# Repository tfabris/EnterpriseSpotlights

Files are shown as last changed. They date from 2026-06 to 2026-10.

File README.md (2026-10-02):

LED Spotlights for Enterprise Refit Models
==========================================
&copy; 2026 by Tony Fabris

https://github.com/tfabris/EnterpriseSpotlights

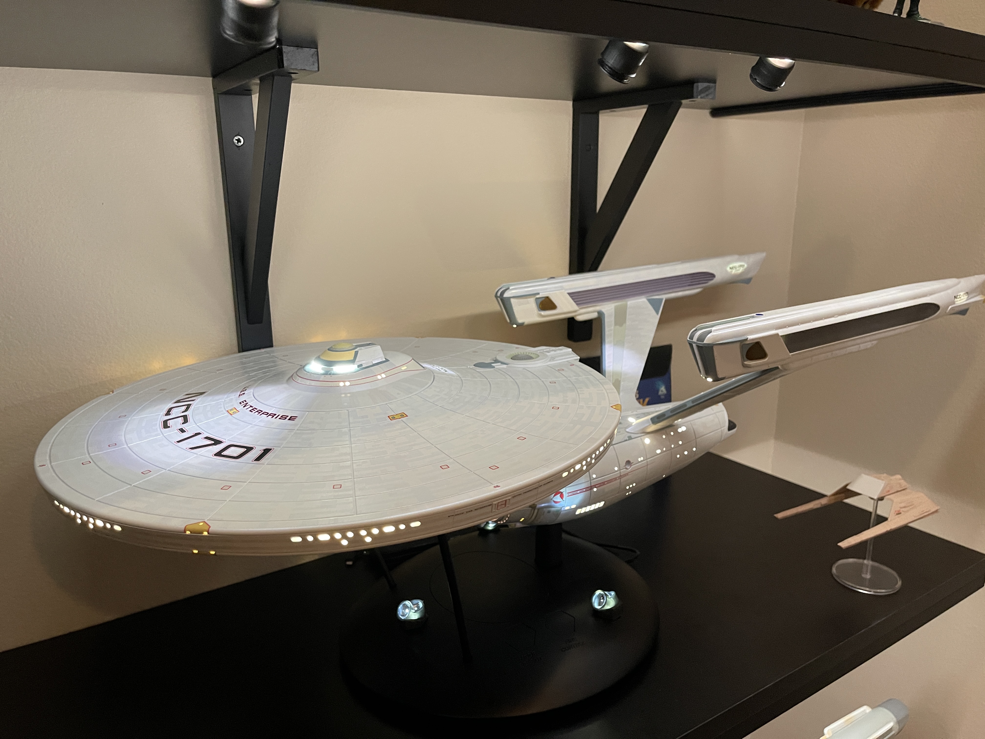
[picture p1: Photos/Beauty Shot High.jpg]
Beauty Shot


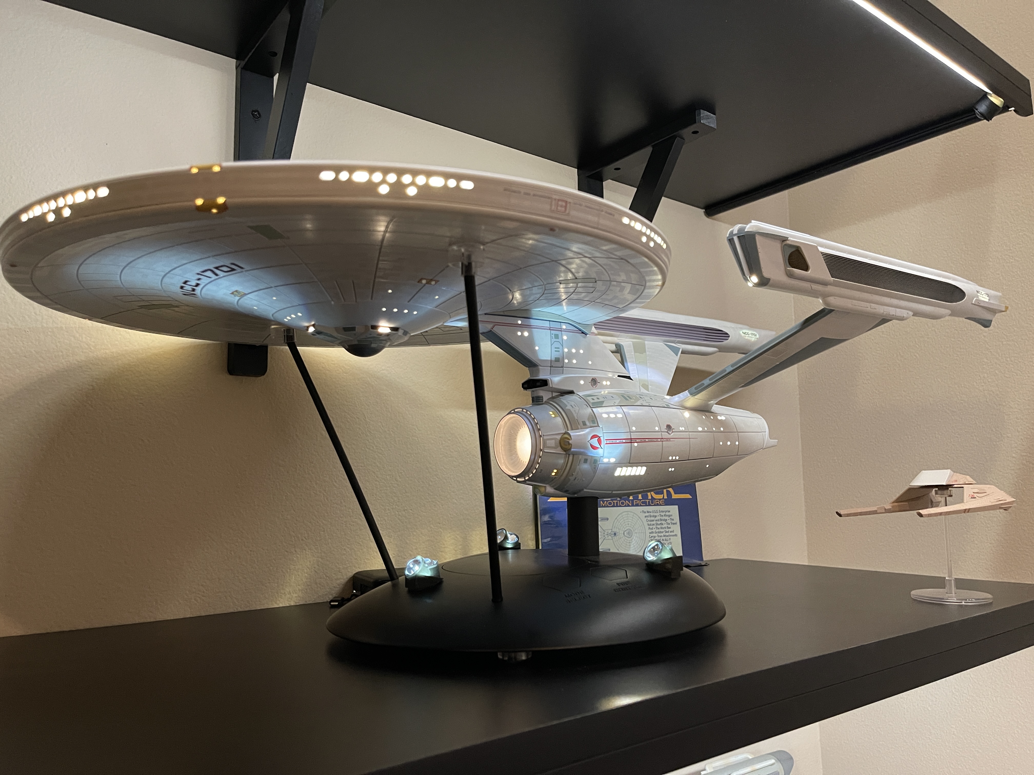
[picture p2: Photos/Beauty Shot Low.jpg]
Beauty Shot
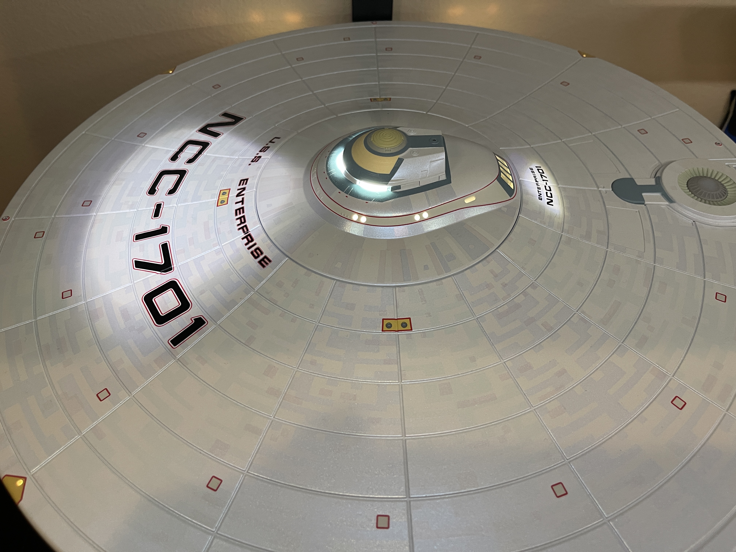
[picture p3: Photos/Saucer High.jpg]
|  |  |
| ---|---|
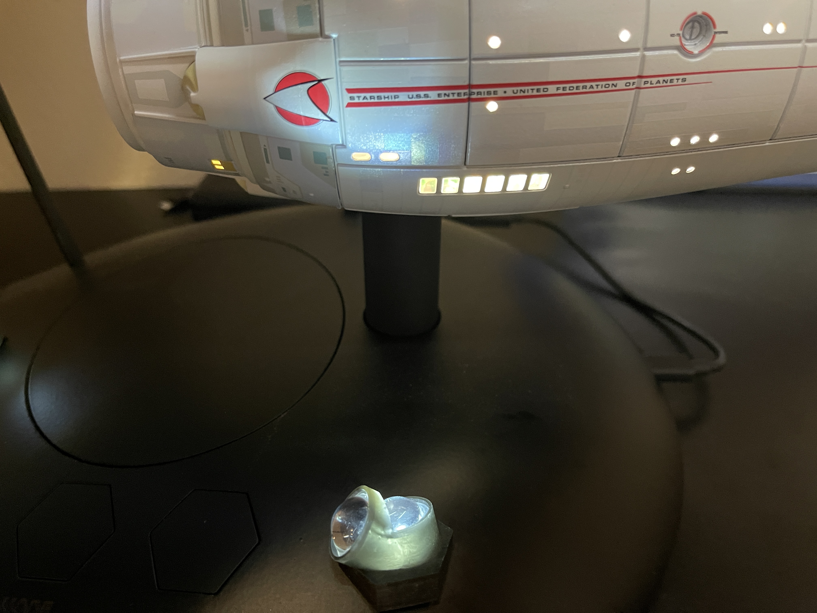
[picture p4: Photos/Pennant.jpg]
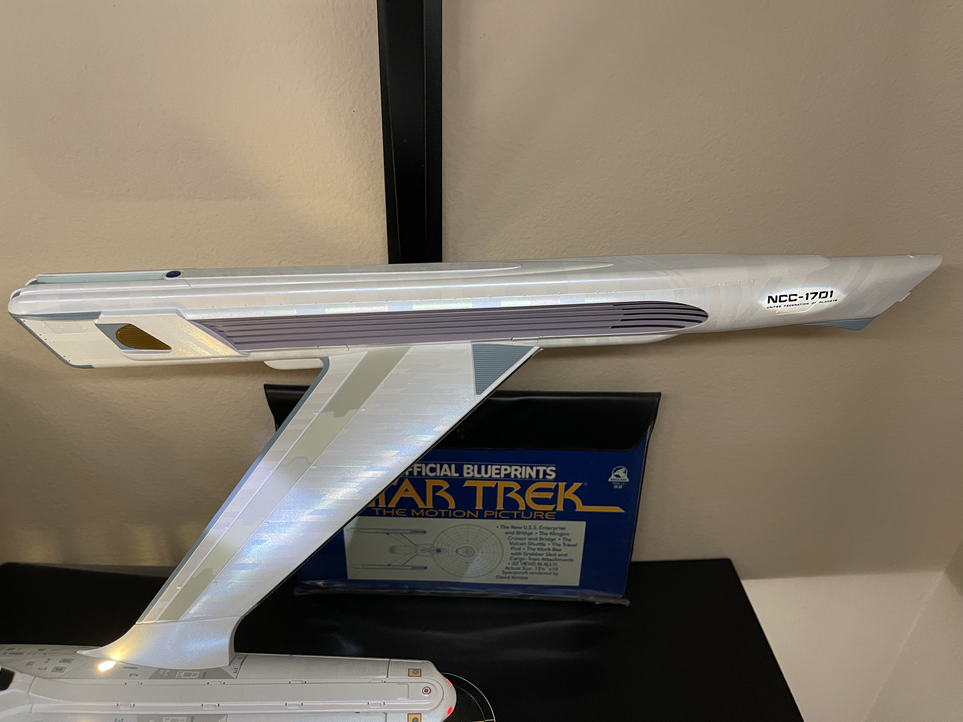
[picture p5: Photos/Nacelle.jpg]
|  |  |

#### This Project:

3D printed assemblies to project hull spotlights onto replica models of the Enterprise Refit from "Star Trek: The Motion Picture". I am using these for my Tomy brand die-cast replica of the Enterprise, but these could also theoretically be repurposed for other similar models such as a Polar Lights Enterprise kit.

#### The Problem:

When making the movie, the special effects artists lit the Enterprise's hull with spotlights. It is implied in the movie that these are all self-lights, like the ones which shine on the insignia of a cruise ship or a military vessel. But in the movie, those spotlights weren't actually self-lights. They were studio lights reflected via off-camera mirrors onto the hull of the Enterprise miniature.

This means it is nearly impossible to truly self-light a model kit or replica of the Refit Enterprise.

Many have tried. Some clever folks use a trick, commonly known as "Raytheon Lighting" among Enterprise kit builders, where LEDs are strategically positioned within the model's interior, to glow through the white plastic. Unfortunately, this technique causes its own difficulties, and it can't be used for my Tomy die-cast replica. Tomy **did** manage to Raytheon-light their outboard nacelle tips, which is incredibly helpful, since those are the most difficult ones to light.

#### My Solution:

Instead of trying to self-light the model, my system uses exterior lights, made of LEDs shining through lenses, to convincingly reproduce the spotlight effects seen in the movie. I chose direct illumination through lenses, rather than using mirrors, because these are less obtrusive than mirrors would have been.

Spotlight Fixtures
------------------

### Upper Spotlights:

I'm displaying my models on large 16" x 36" melamine shelves, and using 45° LED strip channel rails at the edges of the shelves to illuminate the models. Full details about the shelves and LED strips can be found here: https://github.com/tfabris/LED-Controller

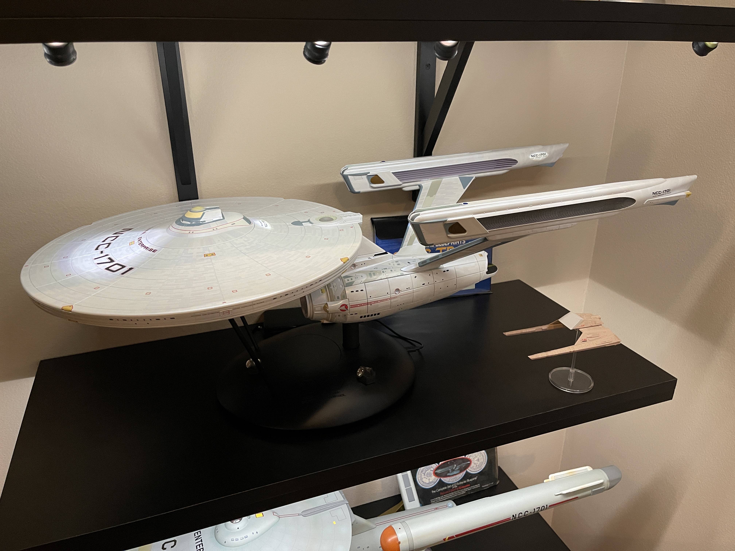
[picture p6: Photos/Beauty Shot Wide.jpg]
Beauty Shot


The LEDs strips I've installed into these channels are individually-addressable WS2812 programmable strips, commonly known as "NeoPixels". Most of the LEDs in the strips are set to a gentle glow to light my models, but, by programming specific single LEDs in the strips to shine brilliant white (I'm using RGB***W*** strips to get the extra ***white*** LEDs), I can mount some lenses in front of those particular LEDs to generate the spotlight effects.

That's where these 3D prints come in: The 3D printed lens holders snap into these rails, and each one holds two lenses in series, to allow a small amount of focusing. The 3D design has a semi ball joint, which allows a small amount of aiming (up/down about 22 degrees from center, and left-right about 10 degrees from center).

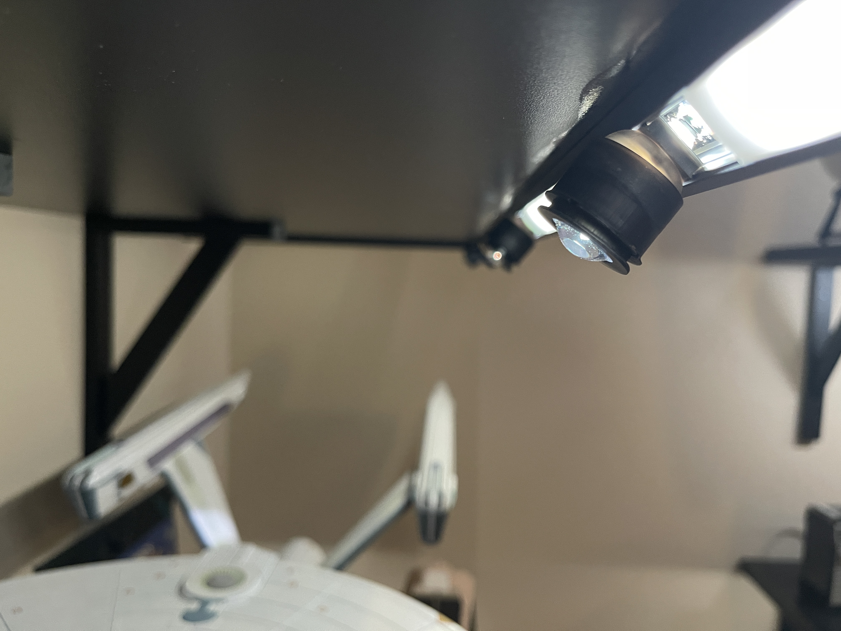
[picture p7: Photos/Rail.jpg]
Rail
    
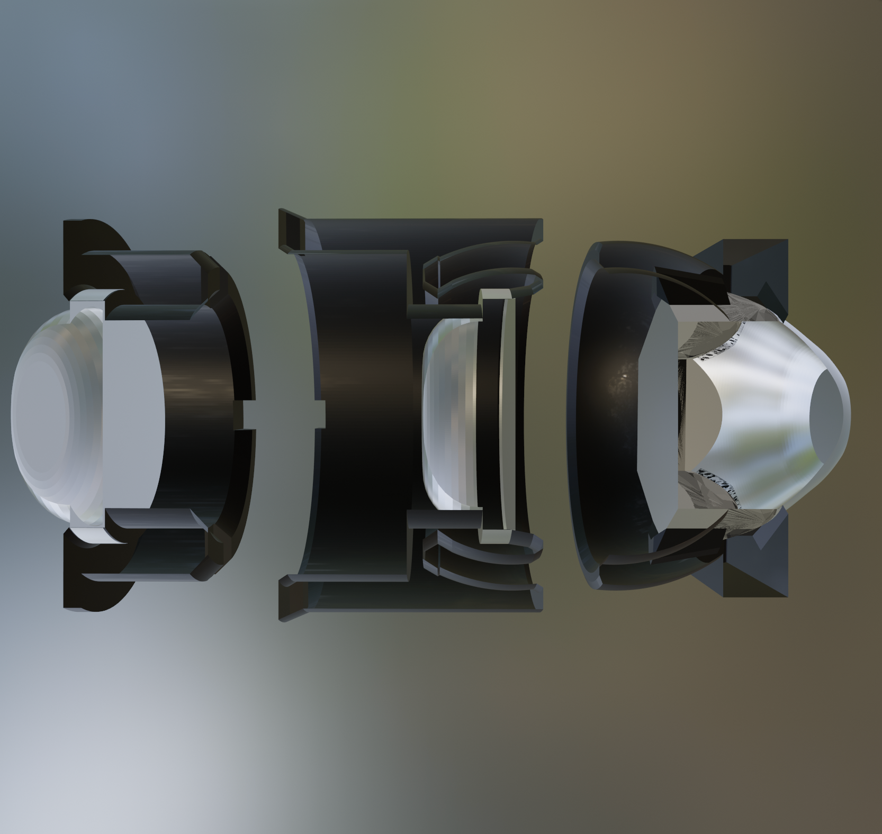
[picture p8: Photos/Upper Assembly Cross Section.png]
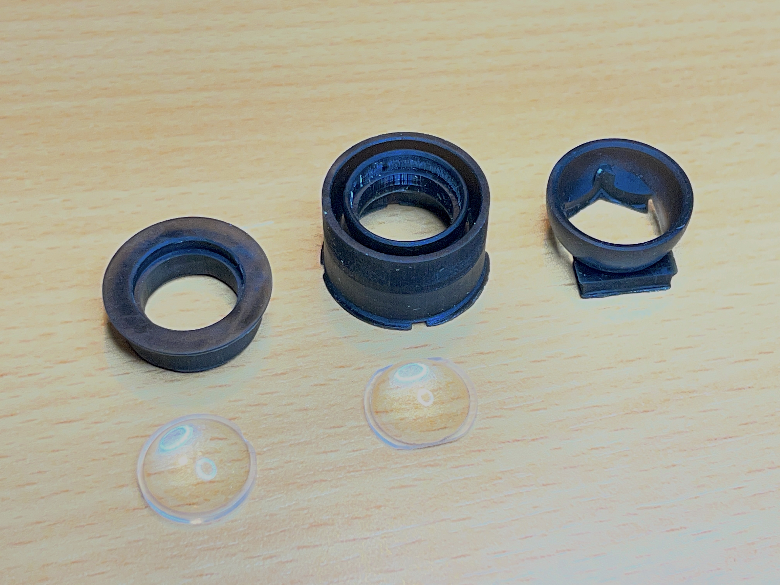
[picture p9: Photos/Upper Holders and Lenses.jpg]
 

To get the special "shapes" of the spotlights (rounded triangles at the front for the top of the saucer, ellipses at the rear for the nacelles), my system uses [gobos](https://en.wikipedia.org/wiki/Gobo_(lighting)) to create the shapes. The gobos in this case are black vinyl stickers, cut to shape on a Cricut machine.

I'm using four spotlight assemblies on the top side of my model, one spotlight each, aimed at the following locations.
- Saucer top front, on the large nameplate and registration number.
- Saucer top rear, on the small nameplate just aft of the windows of the observation lounge.
- Warp pylon, starboard top.
- Warp nacelle, starboard rear, on the registration number the on end tip of the nacelle. Inboard only, because the Tomy collectible already illuminates the outboard ones using self-lighting (thank you, Tomy).

### Lower Spotlights:

My Refit Enterprise is the Tomy brand die-cast replica, released in 2026. That model comes with a special display stand which includes three LED sconces which already light the model from below. I merely needed to add some lenses to the base, to focus their LEDs a little more, via small 3D-printed holders. The holders slip onto the existing hexagonal light sconces in the base.

Note that these lower lens holders are specifically shaped to fit the Tomy base. For some other model, such as a Polar Lights kit, these won't work. If I had one of those models, I would probably need to generate the lower spotlights the same way as the upper ones.

For this Tomy base, I was able to use two lenses per sconce, one lens per spotlight, with no gobos required. By carefully positioning the two lenses near each LED on the base, two spotlights can be generated per LED. So I get six total spotlight effects out of the base of the Tomy model.
- Front-center sconce: Focuses two spotlights on the centerline of the saucer. Forward lens focuses on the registration number, rearward lens focuses on the "Enterprise" nameplate just ahead of the dorsal connector.
- Left and right sconces: Each one focuses two spotlights, one aiming forward, to create the side-spotlights on the underside of the saucer, and one facing the pennants on the sides of the secondary hull (with some overspill onto the dorsal connector).

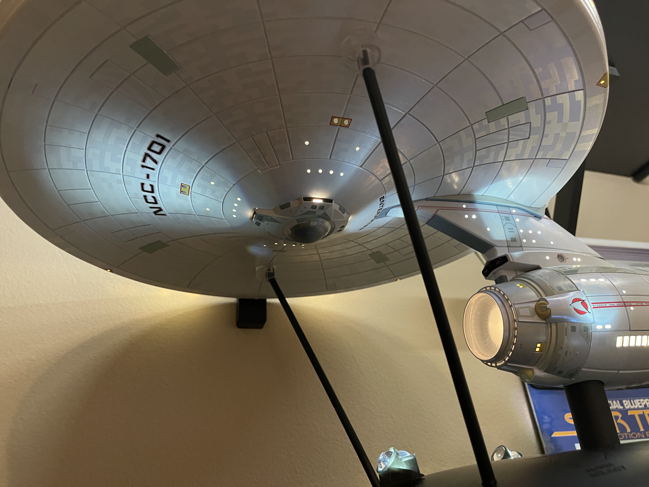
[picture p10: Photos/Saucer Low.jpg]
   

Required Materials
==================

### Hardware:
  
  - A 3D ***resin*** printer:
    - https://www.anycubic.com
  - A Cricut cutting machine:
    - https://cricut.com/ 

### Supplies:

  - "ABS-Like" black resin:
    - https://www.amazon.com/dp/B0FPFZF6V9
    - https://www.amazon.com/dp/B0B12DRYDY
  - 15mm Convex Lenses:
    - https://www.amazon.com/dp/B0BR5PMGWD
    - https://www.amazon.com/dp/B0B2X662B8
    - Make sure to purchase enough lenses: Each spotlight assembly requires two lenses, and it is wise to get extras. I am using a total of 14 lenses (4 upper lens pairs and 3 lower lens pairs).
  - Polymer Optics 12° 15 mm Circular Beam Optic Collimators (either clear or diffused, I recommend diffused):
    - https://luxeonstar.com/product/120-180/
    - https://luxeonstar.com/product/185-180/
    - Make sure to purchase enough collimators: Each upper spotlight assembly requires one collimator, and it is wise to get extras. I am using four collimators for the four upper spotlights.
  - Black vinyl Cricut material:
    - https://www.amazon.com/dp/B0032JJS5O
  - Environmental Lights CS110-2m-B 45° LED strip channel rails, black anodized, end caps sold separately:
    - https://www.environmentallights.com/19358-cs110-2m-b.html
    - https://www.environmentallights.com/19364-el-cap-155-b.html
  - BTF-Lighting RGBW SK6812 LED strip, 60 Pixels/m:
    - https://www.amazon.com/dp/B079ZW1265
  - Power supply and lighting controller. A large variety of options are available to power and control the LED strips. It is a complicated subject; the short version is: I'm using a Mean Well LRS-200-5 200W 5V 40-amp power supply to drive several meters worth of LED strips, and an Arduino Mega 2560 to control them. 
    - https://www.amazon.com/dp/B0131V99BA
    - https://www.amazon.com/dp/B07TGF9VMQ
    - ***Note:*** Don't try to drive more than a handful of LEDs "directly" off of an Arduino, without a separate power supply. For LED strips of any length, a proper power supply is required, to prevent frying the Arduino board.
  - Black cable channels 2 x 39 inches each:
    - https://www.amazon.com/D-Line-Raceway-1D3015B-Surface-Electrical/dp/B09CKV1YGH
  - Blue Sea System ST Blade Fuse Block, 6 Circuit:
    - https://www.amazon.com/dp/B006VELERM  
    - https://quinled.info/2019/02/18/use-fuses-for-increased-safety/

### Software:

  - The source files for these 3D models:
    - https://github.com/tfabris/EnterpriseSpotlights/archive/refs/heads/master.zip
  - A slicer program - I'm using Chitubox Basic v1.9.4 at the moment:
    - https://www.chitubox.com/en/download/chitubox-free
  - Optional: Blender - I'm using v3.6 at the moment:
    - https://www.blender.org/
  - Cricut Design Space:
    - https://design.cricut.com/
  - Cricut design files:
    - https://design.cricut.com/landing/project-detail/69b8c28240372784c3de23df
  - Lighting control:
    - Indivdual LED color controls are required. Either use pre-built lighting control modules or create a custom-coded module. I'm using the FastLED library for the Arduino with my own custom code. Full details of my custom LED system are here:
      - https://github.com/tfabris/LED-Controller

3D Printing Lens Holders
========================

Print using a resin printer with ABS-Like resin in the Black color. 

- To print, import these files into the slicer program:
  - "Upper Spotlights.stl"
  - "Lower Spotlights.stl"
- Duplicate the upper spotlight objects in the slicer for as many as needed. I am using four upper spotlight assemblies.
- Slice and print.

#### IMPORTANT:
- ***Do not rotate the parts*** for printing, they should already be in the correct orientation.
- ***Do not add supports*** for printing, just print the parts directly to the print bed, they are designed to be printed without any supports.

Gobos
=====

Cut the gobo sticker material on the Cricut machine, based on the design file. The vinyl material, and the design file, are linked above.

Assembly
========

#### Modify the Polymer Optics collimators:

- Remove the plastic "hex holders" from the collimators: The collimators come with small plastic shrouds, remove the shrouds so that they're just the pure collimator lenses.

- Locate the two opposite sides of the hex flat faces of the collimators which are not perfectly smooth (where they were cut off a molding sprue).

- Sand those faces down to remove about 0.25mm of thickness from those faces. The collimators need to be ever so slightly narrower in one direction, so they fit into the rail.

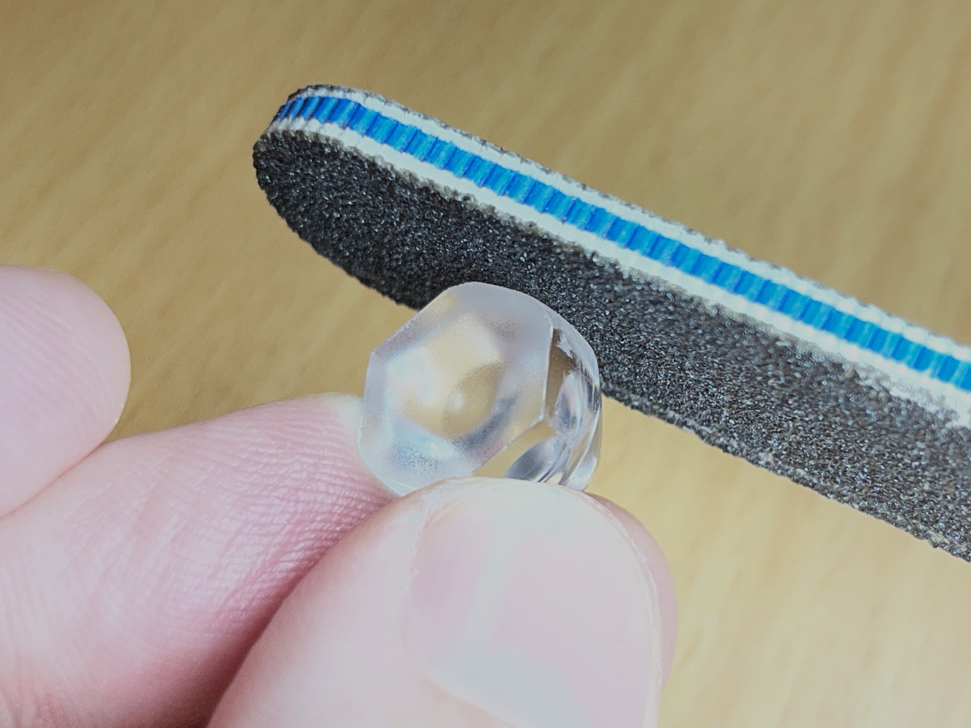
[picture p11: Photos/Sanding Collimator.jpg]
Sanding Collimator
  

- Sand the upper pointy corners of those same two faces. Sand away about 1mm of pointyness off of those four corners. This is to make room for the shroud to fully rotate on the ball joint, so that the spotlight can be aimed. Without sanding these corners away, the shroud can aim about 12 degrees up/down, with these corners sanded away, it can aim about 22 degrees up/down. 

- ***IMPORTANT***: Leave the other two corners ***un-sanded*** because they must stay pointy, to snap the collimator into the ball joint assembly in the next step.

#### Assemble Upper Spotlights:

- Snap the collimator into the ball joint part, with the pointy un-sanded corners fitting into the two snap retainers, and the sanded sides protruding visibly down the two rail gaps on the lower section.

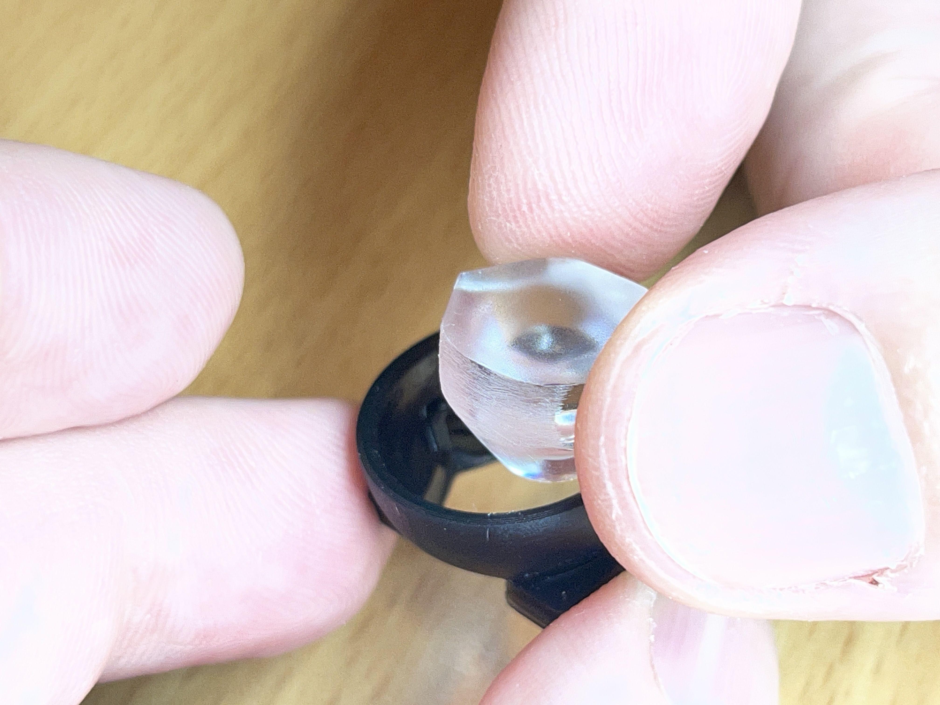
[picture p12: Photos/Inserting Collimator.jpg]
Inserting Collimator
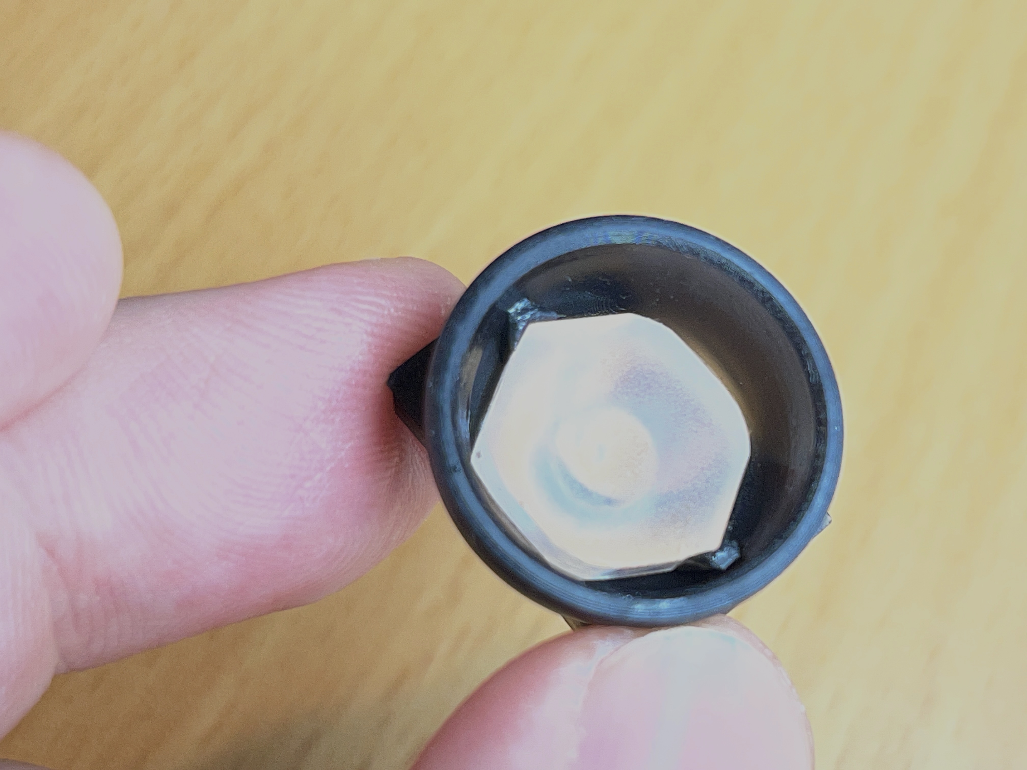
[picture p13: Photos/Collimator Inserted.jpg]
Collimator Inserted
|    |    |
| ---|---|

- Trim flashing off of the edges of the lenses, if any. Make sure the lenses are clean, as they will magnify any dust and debris into the spotlight image.

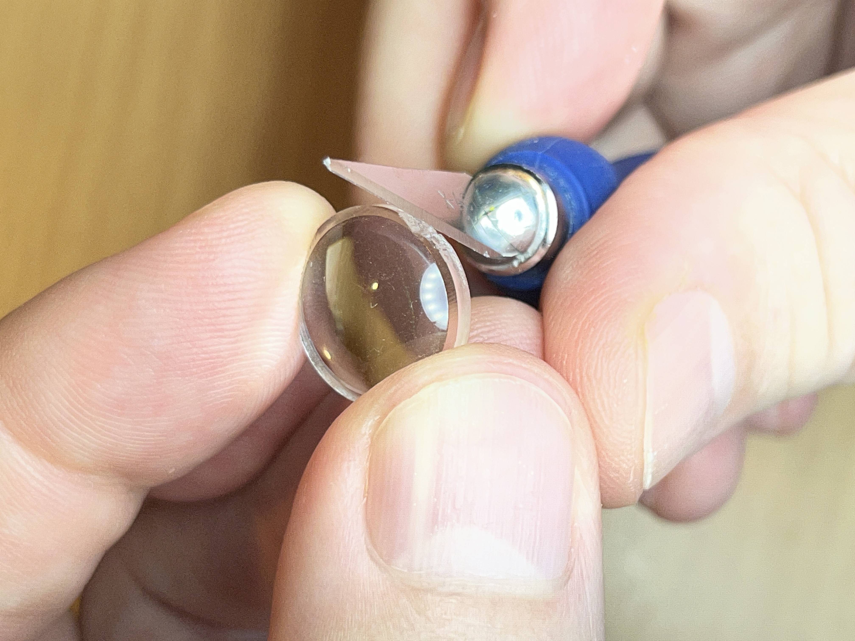
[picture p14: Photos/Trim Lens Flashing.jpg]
Trim Lens Flashing


- Stick the desired Cricut gobo sticker onto the flat side of one of the lenses.

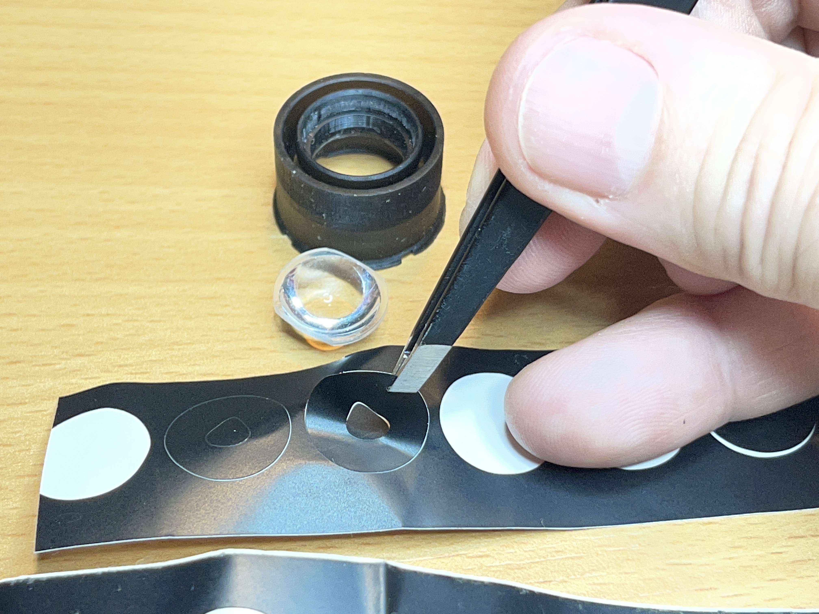
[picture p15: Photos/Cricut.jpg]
Cricut
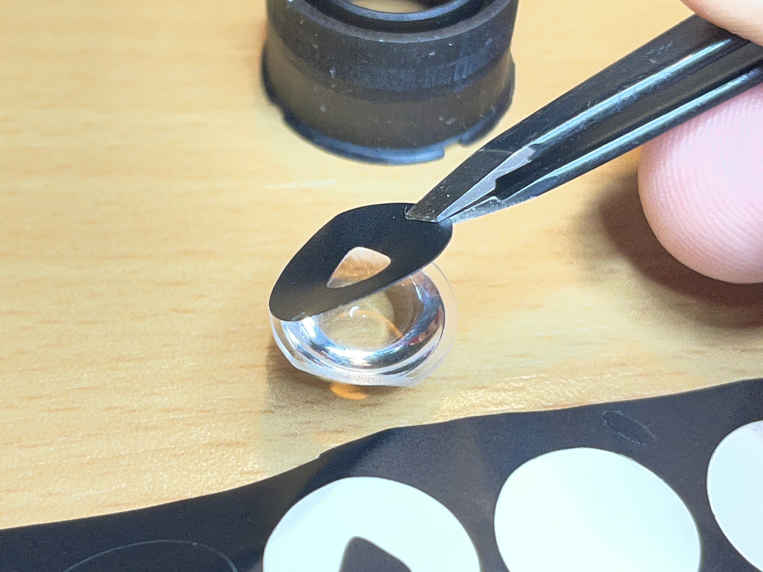
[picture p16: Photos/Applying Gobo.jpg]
Applying Gobo
|   |    |
| ---|---|

- Press-fit the gobo'd lens into the shroud part, lens bulge facing into the shroud, lens flat side facing the side which attaches to the Ball Joint part. 

- ***Note:*** All of the lens press-fits for these assemblies may be very tight, depending on the brand of lens. Ensure that the lens surface itself is not scratched during the press fitting process. A tiny amount of sanding on the edge lip of the lenses may be needed to ensure they can fit, using caution not to damage the lenses. Best practice is to sand only one or two sections of the edge, rather than the entire circumference.

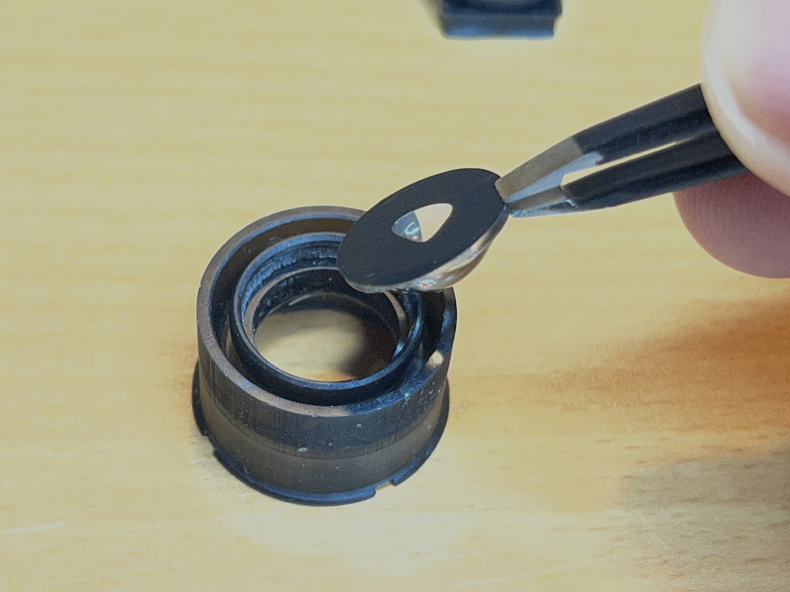
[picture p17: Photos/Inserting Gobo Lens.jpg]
Inserting Gobo Lens
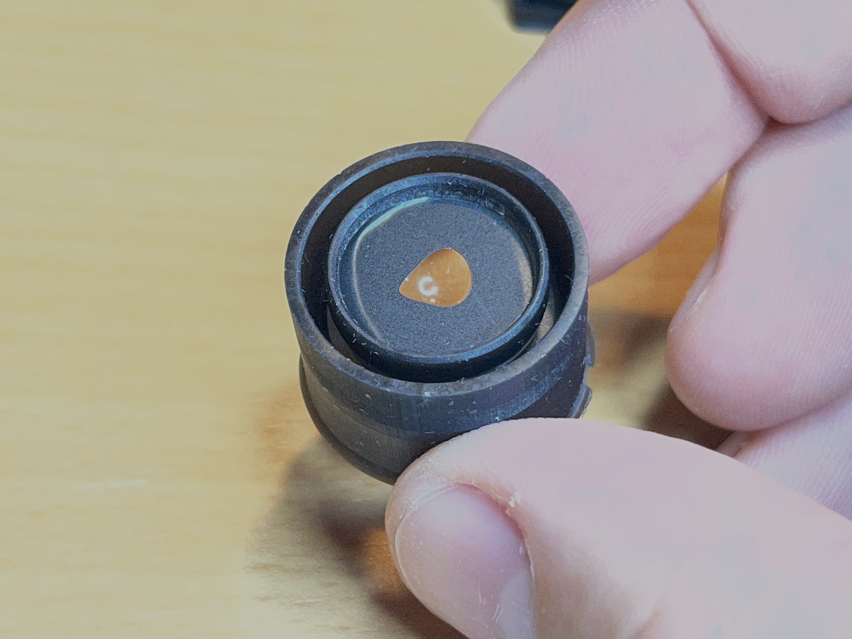
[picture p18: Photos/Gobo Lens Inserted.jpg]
Gobo Lens Inserted
|    |    |
| ---|---|

- Press-fit a lens into the focusing lens part, lens bulge facing out of the part. 

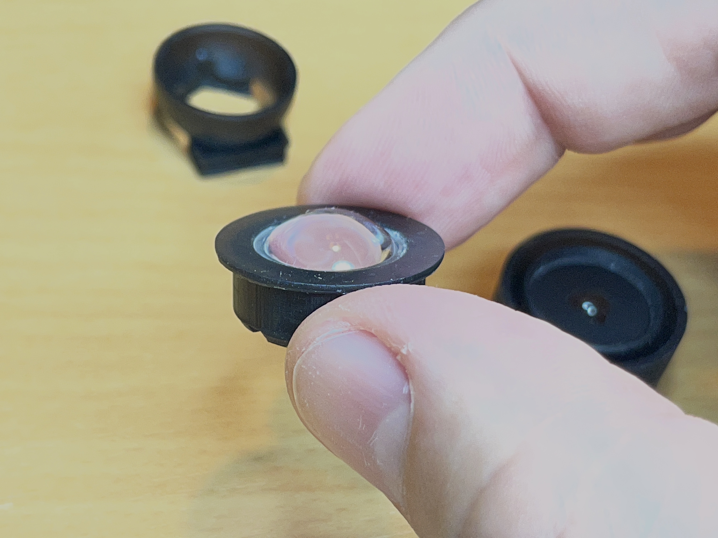
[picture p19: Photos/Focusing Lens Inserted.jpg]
Focusing Lens Inserted


- Slide the focusing lens part into the shroud part, ensure that it can slide in and out slightly, to adjust its depth, to focus the gobo image onto the desired object.

- Press the shroud onto the ball joint carefully. Ensure it can rotate and angle smoothly.

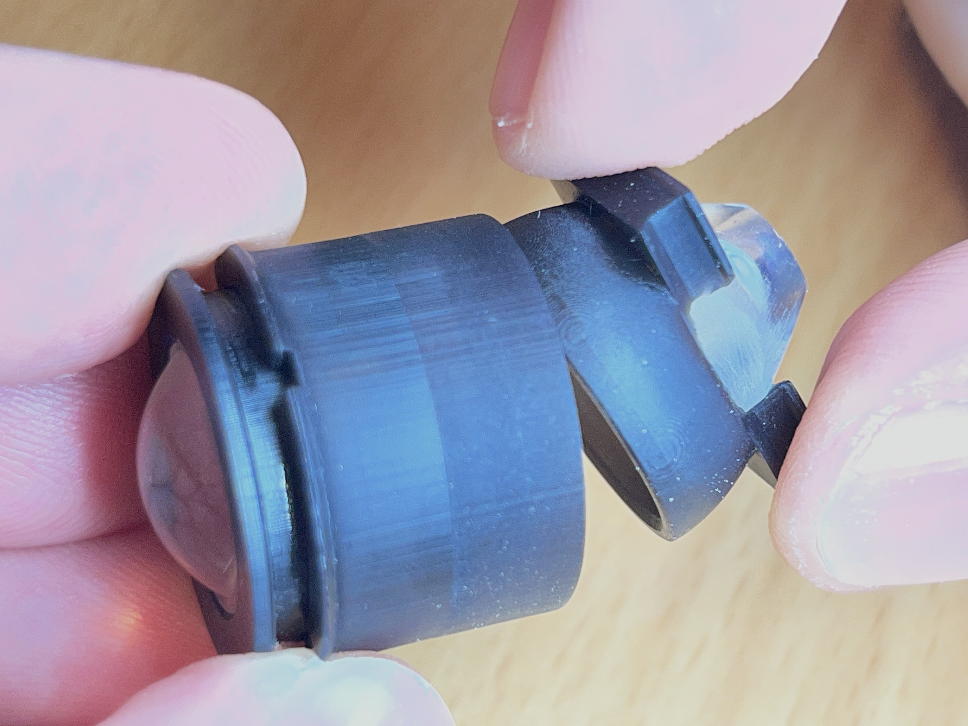
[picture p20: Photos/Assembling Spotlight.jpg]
Assembling Spotlight


- Snap the ball joint part into the LED railing. Pictured: A cross section of the rail (without LEDs) to show how it snaps into place. 

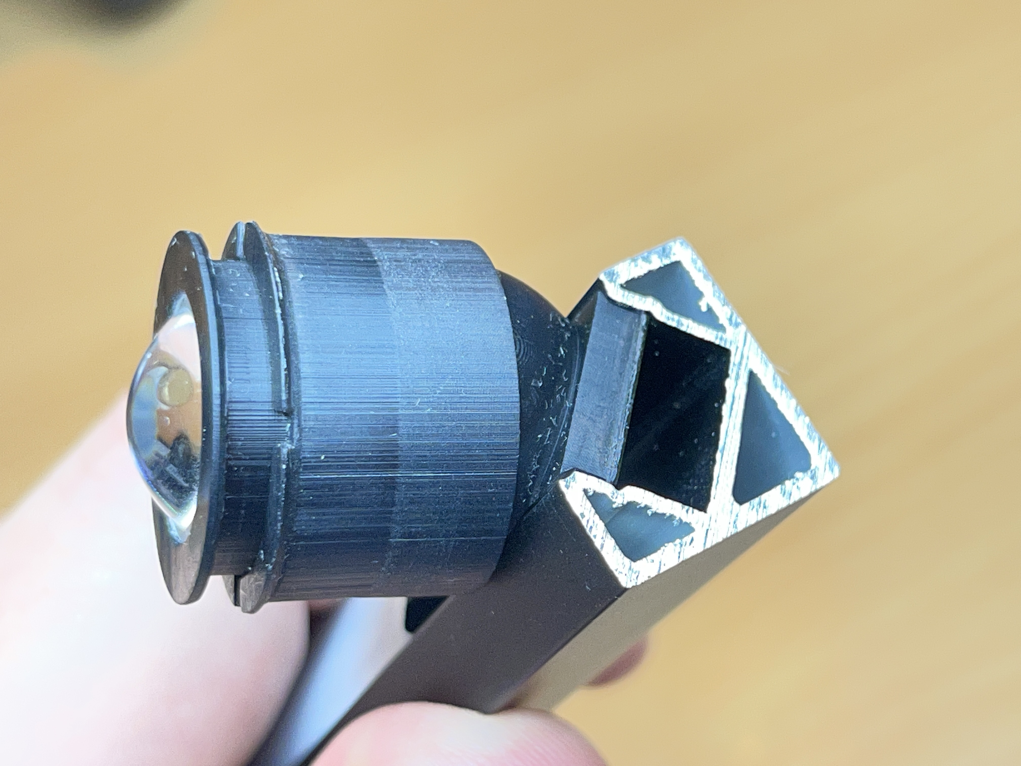
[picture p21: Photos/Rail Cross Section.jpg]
Rail Cross Section


- Adjust the position of the spotlight along the rail until it is centered above the desired LED. The spotlight should be moveable by sliding along the rail (although it is a tight fit).

- The bottom tip of the collimator will only barely clear the top surface of the LEDs stuck onto the rails. If you are trying to slide the spotlight along the rail and it's stuck, check if it might be the collimator getting hung up on an LED.

#### Assemble Lower Spotlights:

- Press-fit two lenses into each of the three lower lens holders. Ensure the lenses are fully seated in the holders, but be careful not to break the fragile resin-printed holders when press-fitting.

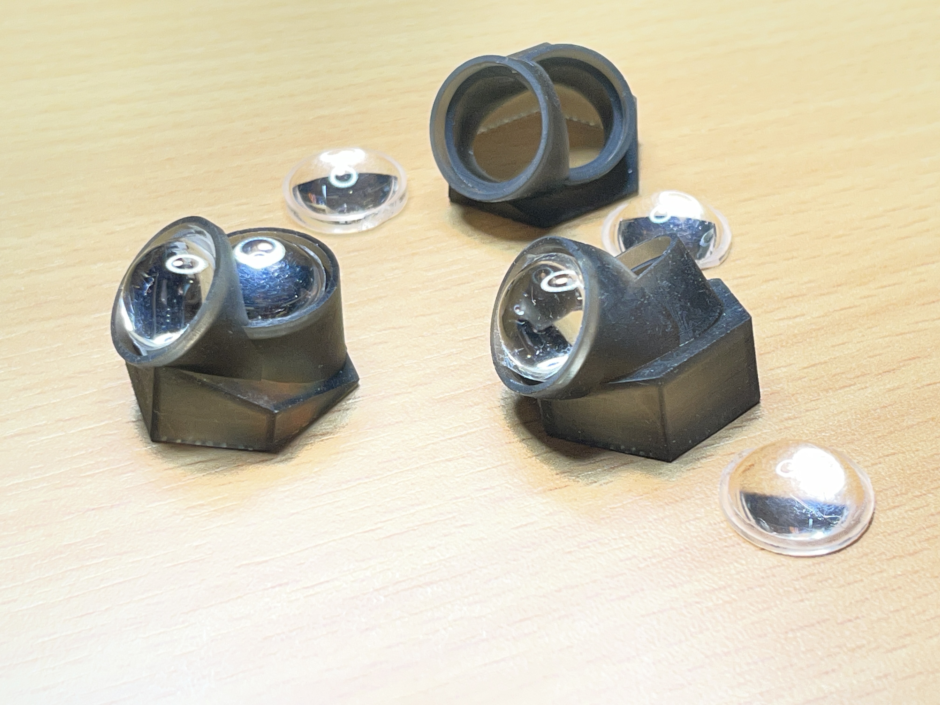
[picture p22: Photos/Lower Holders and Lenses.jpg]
Lower Holders and Lenses


- Place the lens holders over the three hexagonal LED sconces in the base of the model. Identify which holders go atop which sconce on the base: In the photo above, clockwise from top, they fit the right (starboard) sconce, the left (port) sconce, and the front/center (bow) sconce.

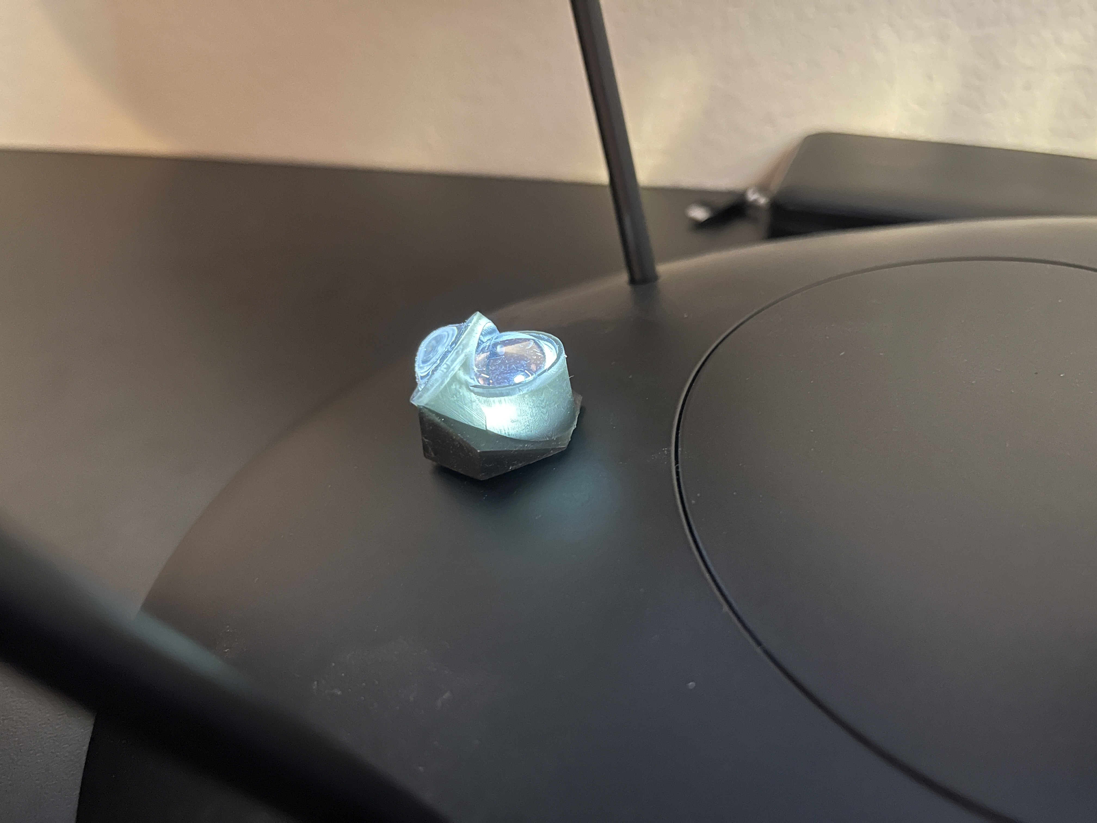
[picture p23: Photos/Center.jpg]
Center
 

Making Adjustments
==================

#### Aiming Lower Spotlights:

The lower lens holders are not aimable. They have been pre-aimed based on my particular model. I expect that all of the Tomy Enterprises should have the same base shape and LED positions, but there's no way for me to tell if other models will be slightly different. If modifications are needed, change the lens tube angles on the lower spotlights in the original Blender file "Lower Spotlights.blend" (Blender expertise required for this) and then re-export and re-print the parts.

If changing the lens tube angles in the Blender file, recheck the following before exporting and reprinting:
- Before editing, make sure that the "Transform Orientation" menu (top center) is set to "Local". The tube angles must all be locally rotated in their child relationship to the flat tops of the hexagonal bases. 
- Optional: Since the bases are already rotated X=25° for printing to the bed, then before editing, rotate the bases to X=0°, then do your editing, then put them back to X=25°, so that their bases lay flat to the print bed for exporting and printing.
- When editing, ensure the lenses will not intersect each other physically, since they are all very close to each other.
- When editing, ensure the lens tubes and "cutter" parts are all working correctly for all their boolean operations, for example, nothing is cut less or more than it should be (note that the boolean cutter parts are hidden, and buried in the item hierarchy inside other objects). It may be necessary to adjust the bottom polygon of each tube or cutter, so that everything works correctly again after the angles are changed.

#### Aiming Upper Spotlights:

First, ensure that the spotlights are getting the full brightness out of their LEDs. Slide each spotlight assembly slightly left and right along the LED rail channel (they should be fitting very tightly but still moveable). View the projected image of the LED shining through the spotlight, to tell whether the spotlight is perfectly centered and at its brightest.

Once centered, rotate, aim, and focus each spotlight until it's positioned perfectly on the model. I try to defocus my spotlights ever-so-slightly, to give them a soft edge on the model. Focusing is done by sliding the focusing lens slightly in or out.

#### Changing Gobo Shapes and Sizes:

The Cricut gobo design file is based on my particular model and shelves, so the gobos might need to be re-made if distances and/or angles change. If creating new gobos, use the following steps in the Cricut Design Space app:

- Create an outer circle which is 15.08mm (1.508cm or 0.59375 inches) in diameter. Press "Shapes", Select the circle shape, and once the circle has appeared on the canvas, press the SIZE button in the toolbar, and enter the desired size.

- Create an ellipse or other desired shape, for the center cutout, using similar steps. Resize this second shape to be the desired size. Move and position it so that it sits in the center of the circle.

- Drag-select both of the objects so they are selected at the same time.

- In the toolbar, press "Align" and choose "Center". The second shape is now centered in the circle.

- In the toolbar, press "Combine" (it may be hidden under a "More" menu) and select "Subtract".

- The circle should now have the second shape cut out of it.

- Recommend creating several versions of each gobo, with slightly different sizes of the cutout shape, for easier experimentation and trial-and-error.

To create a new cutout shape for the triangular-shaped spotlights (such as on the upper saucer section), my technique was:

- Create three oval shapes of different sizes. Smaller sizes to create the more pointy end of the spotlight shape, larger sizes to create the more rounded ends of the spotlight shape. Use ***oval*** shapes instead of ellipse shapes, which allows them to have straight sides yet also have rounded ends.

- Rotate and position them so that their ends overlap to form the desired triangular shape. 

- Remember to make the overall shape asymmetrically "lopsided" to compensate for the oblique angle from which the spotlight will be shining upon the saucer.

- The shape will likely have a "gap" in the center which will need to be covered up with a circle.

- Select all of those shapes and press "Combine" and select "Unite" to make them into a single unbroken shape.

- Duplicate that shape, then choose "Flip" to make a mirrored version of it. 

- Resize those shapes to the desired size. Recommend creating multiple sizes for greater ease of experimentation.

- Create new circles with those shapes inside, using the "Subtract" technique described above.

- The reason I create two mirrored versions: I always forget which direction the "lopsided-ness" needs to be when I get it onto the actual model, so I need to have both sets of gobos on hand, so I can try them both out in physical space.

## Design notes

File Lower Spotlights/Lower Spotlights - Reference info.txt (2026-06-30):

-----------------------------------------------------------------------------
Tomy Refit Enterprise, base light lens focusers, lens holders for 3D printing

             Blender creation notes and reference information
-----------------------------------------------------------------------------
                          Lower Spotlight Set
-----------------------------------------------------------------------------

Designed to fit a set of 15mm x 5mm lenses, similar to these:
- https://www.amazon.com/dp/B0BR5PMGWD
- https://www.amazon.com/dp/B0B2X662B8

Outer diameter: 15.08mm
Inner diameter: 13mm
Height: 5.8mm
Side thickness: 1.3mm
Dome diameter: 13.0402mm
Lip thickness: 1.81mm
Focal length: 10mm

Measurement note:
- All measurements below are in Millimeters in the real world, but in Blender these values will show as Meters. They will be automatically converted to millimeters when the STL file is imported into the slicer. (At least, Chitubox works that way, not sure about others.)

--------------------
Base hexagon shrouds
--------------------
- Outermost vertices diameter: 26.76
- Wall Thickness: 2

Base Hexagon Creation Steps:
- Add, Cylinder
- Radius: 13.38
- Vertices: 6
- Depth: 20
- End caps: N-gon
- Use edit mode to delete the bottom cap, faces only    
- Back in object mode, add solidify modifier with thickness of 2
- APPLY IT.
- NAMES: "Base Center" "Base Left"

IMPORTANT: Use the ITEM menu to rotate the hexagon Z-axis 30 degrees so that flat faces are bisected by the green Y axis lines, and points are along the red X axis line. Then apply all transforms to it (ctrl-A)

IMPORTANT: From the "Numpad-3" side view, go into edit mode and grab the faces of the bottom of the hexagon and drag them westward so that the angle of the hexagon sides tilts at 76.50 degrees to match the angle of the hexagon light sconces on the model stand. Here is how to show that angle with enough decimal points:
- In blender preferences, under Add-Ons, search for and enable the addon: "3D View: MeasureIt"
- In edit mode
- Select Vertex Selection tool
- Select three vertices, in this order: (1) click left top hexagon corner, hold shift, (2) click right top hexagon corner, hold shift, (3) click right bottom hexagon corner. You are selecting these vertices of the hexagon (as viewed from above):
     /\
    /  \
   /    \
   |    |
   |    |
 1 \    / 2
    \  /   3
     \/
- Select the View tab in the view panel options on the right edge of the playfield.
- Expand "MeasureIt Tools", press SHOW, press ANGLE.
- It should currently show an angle of 90 degrees before you make any changes to the hexagon's shape. If not, you've selected the wrong vertices.
- Use edit mode tools, switch to Face select mode, select all of the bottom edge faces, then using the side view (Numpad 3) G-drag those bottom faces westward (press y to constrain to y)
- As you drag westward (Y) the number should change, if it does not, fiddle with the MeasureIt Tools some more, maybe pressing Show, Angle, again, and/or reselecting those vertices to get it to stay up. Not sure what order I did those steps in, but I eventually got the angle of those three vertices to stay on screen while I dragged.
- Drag until you make the angle read 76.50.
- Hide MeasureIt Tools.

Angled slice-off of the base:
- Back in Object mode
- Create a large 50m cutter cube, angle it -25 degrees
- NAME: "Base Angle Cutter"
- Use the side view (numpad 3)
- Switch to wire frame view mode.
- Position the cube so that it intersects the inner angle between the rear ceiling and wall. 
- Boolean diff the hexagonal base with that angled cube.
- Check and see if the boolean looks right (the hexagon base edges must still be solid. If not, try an EXACT bool instead of a FAST bool.
- Once it looks right, hide the angled cutter cube.
- APPLY THE BOOL and delete the cutter cube.

Create a cube for cleaning up the bottom sections of the tubes later:
- Create a oversized cutter cube, do not rotate it.
- NAME: "Tube Cutter Base"
- Use the side view (numpad 3)
- Switch to wire frame view mode
- Perform the same "76.50 Angle" procedure on this cube as you did on the hexagon base.
- From the side view (numpad 3)...
- Move the cube in the Z direction so that its top surface falls just barely within the flat ceiling of the hexagon base interior.
- Move the cube in the Y direction westward so that its eastward face falls just barely within the east wall of the hexagon base interior.
- Make it a child of the "Base" hexagon. How to child an object:
  - Select the child object (in this case the cutter cube).
  - Select the parent object (in this case the base hexagon).
  - Press CONTROL-P for "parent"
  - Choose "Object"
  - Make sure the "Keep transform" tickybox is UNchecked.
- Once parented, hide the cutter cube.
- Do this for both bases.

---------------
Tubes:
---------------
Outer diameter: 16.76
Wall Thickness: 0.85

Tube creation steps:
- Add, Cylinder
- Vertices: 128
- Radius: 8.38
- Depth: 30
- Cap fill type: N-Gon
  - Add inset recess to top of large tube for press-fitting the lens.
    - Aiming for diameter of 15.06 radius of 7.53 on the recess which makes the edge lip thickness 0.85
    - In Edit Mode, select top face and press I (inset) and drag to make the inset. Enter thickness value of 0.85 in the dialog.
    - With the inner flat face still selected, press E (extrude) and drag down (Z constraint will likely be activated automatically by default). Enter -2m in the Z box in the dialog.
Cutter:
- Add, Cylinder
- Vertices: 128
- Radius 7
- Depth: 40
- Cap fill type: N-Gon

Do not delete the cutters, make them a CHILD of the tube so that it moves and rotates with the tube. The reason for this is so that you can also use it to cut the holes in the base and the other angled tubes.
- Select the cutter tube (child)
- SHIFT-select the main tube (parent)
- Press CTRL-P to set the parent.
  - Set parent to "Object".
  - Make sure the "Keep transform" tickybox is UNchecked.

-------------------
NOTE: Other Cutters
-------------------
I also added secondary and tertiary cutters, and lens dome cutters, to handle the ways that the lenses tend to overlap each other once they were correctly positioned. This was tricky and too much to detail here. 

------------------
Add Tube Booleans
------------------
These are all Difference bools, Solver: Fast, DO NOT "APPLY" ANY OF THESE, LEAVE THEM LIVE. Check that each one of these booleans looks correct and that the geometry didn't get glitched up. If there are glitches, see if "Solver: Exact" fixes the glitch, but generally try to leave them on the Fast solver if possible.

- Each tube:
  - Cutter tube corresponding to that tube.
  - Primary and secondary cutter tubes from OTHER tubes residing in the same base.
  - Front tube only: Tertiart cutter cube.
  - "Tube Cutter Base" for that base.
- Hexagonal base:
  - Primary and secondary cutter tubes from all tubes which reside in the same base.

------------------
Organization
------------------
Make each of the tubes a CHILD of their base, using the parenting procedures described above. Hierarchy should be like this:
  Base Center
    Center Tube Cutter Base
    Center Back
      Center Back Cutter
      Center Back Lens Dome Cutter
      Center Back Secondary Cutter
    Center Front
      Center Front Cutter
      Center Front Secondary Cutter
      Center Tertiary Cutter
(And then the same pattern for the left unit.)

--------------------
Mirror the Left Unit
--------------------
- Shift-A (add)
- Empty->Main Axis
- Move that Empty object along the X axis so that it's away from the center of the world, and is to the side of the object you want to mirror. Move it to where you want the "hinge rotation point" of the mirror to exist, next to the base object.
- How to mirror an object:
  - Select the base object that you want to mirror.
  - Add modifier: "Mirror".
  - Select the "Mirror Object" field of that modifier, choose that "Empty" object that you just created and positioned a moment ago.
  - Select the AXIS of the mirror, it should be the axis along which you placed that Empty object.
  - A perfect mirror copy of the object should now be sitting next to the 
- Repeat the mirroring procedure for all three objects (base, front tube, back tube).

--------------------------------------------------------------------
Tube angles at time of this writing (might be changed, check these):
--------------------------------------------------------------------

Center light tubes:
Center front:
-65 degrees X axis
Center back:
-23 degrees X axis

Left light tubes:
Left front:
+52 degrees Y axis, -3 degrees Z axis
Left back:
+16 degrees X axis, +6 degrees Y axis, +8 degrees Z axis

If changing the tube angles, recheck the following:

- Before editing, make sure that the "Transform Orientation" menu (top center) is set to "Local". The tube angles must all be locally rotated in their child relationship to the flat tops of the hexagonal bases. 
- Since the bases are already rotated X=25° for printing, then before editing, rotate the bases to X=0°, then do your editing, then put them back to X=25° for printing again.
- When editing, ensure the lenses will not intersect each other physically, they are all very close to each other.
- When editing, ensure the lens tubes and "cutter" parts are all working correctly for all their boolean operations, for example, nothing is cut less or more than it should be (the cutter parts are hidden, and buried in the item hierarchy inside other objects). It may be necessary to adjust the bottom polygon of each tube or cutter, so that everything works correctly again after the angles are changed.

-----------------------
Exporting for printing:
-----------------------

Ensure the bases have been rotated correctly, for the purpose of printing straight to the print bed without any supports:

- Select the Base hexagon object for the Center base. Make sure nothing else is selected.
- In the ITEM panel, ensure "Rotation:" X axis only, is 25 degrees.
- This should put the bottom of the hexagon flat parallel with the bottom world plane. The tubes should go along with it if the parenting process was done correctly.
- Repeat this for the Left base. Its mirror should follow along as well.
- Export all the printable objects (two bases and their tubes, plus the mirror of the left base).
- Export as STL.

--------
PRINTING
--------
Print with a resin printer.
Print using black-colored ABS-Like resin.
Print with NO SUPPORTS, just go straight to the print bed.

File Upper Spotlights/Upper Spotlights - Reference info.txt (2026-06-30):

-----------------------------------------------------------------------------
Tomy Refit Enterprise, base light lens focusers, lens holders for 3D printing

             Blender creation notes and reference information
-----------------------------------------------------------------------------
                          Upper Spotlight Set
-----------------------------------------------------------------------------

Designed to fit a set of 15mm x 5mm lenses, similar to these:
- https://www.amazon.com/dp/B0BR5PMGWD
- https://www.amazon.com/dp/B0B2X662B8

Outer diameter: 15.08mm
Inner diameter: 13mm
Height: 5.8mm
Side thickness: 1.3mm
Dome diameter: 13.0402mm
Lip thickness: 1.81mm
Focal length: 10mm

Measurement note:
- All measurements below are in Millimeters in the real world, but in Blender these values will show as Meters. They will be automatically converted to millimeters when the STL file is imported into the slicer. (At least, Chitubox works that way, not sure about others.)

Measurements - Snap-in Rail Holders
-----------------------------------

RGBW LED strip total thickness (max protrusion distance from back plate where it's peel-stickered onto the back plate): 1.9
RGBW LED strip width: 10
RGBW LED strip gap between two LEDs: supposedly 12 but maybe a hair smaller.
RGBW LED block diameter: supposedly 4.6666666 but maybe a hair bigger. Doing 4.8 in my model simulation.
RGBW LED strip center distance between two LEDs: 16.66666666

Rail channel width at back plate: 12.2
Rail channel width above the notch: 12.8
Rail channel width inside the notch: 13.2 half of which is 6.6
Rail channel max depth from outer edge: 9.6
Rail channel notch center distance from back plate: 5.95
Rail channel 45 degree bevel distance from notch center to edge of bevel: 2.65

Polymer Optics Hexagonal Collimators:
- Diameter, flat hexagon sides: 12.9
- Diameter, pointy hexagon sides: 14.9
- Depth: 10
- Depth of flat hexagon cuts on the sides of the dome: 5mm widest, 3.3mm narrowest
- Hole diameter in dome: 6mm at extreme edge, I'm making my inserts 5.8mm diameter to ensure they fit.
- Hole depth in dome (center of reverse dome inside hole) - Hard to measure. Anywhere from 1.8-3.3mm I think. I went with 2.1 mm for my inserts and it worked out OK. The inserts could have been a hair deeper but this was good enough.

Measurements - Gobos for Snap-in Rail Holders
---------------------------------------------
Gobo primary, stuck to the back of the first lens: 15.08mm (1.508cm) outer circle size.
Cricut design files for cutting gobos:
https://design.cricut.com/landing/project-detail/69b8c28240372784c3de23df

--------
PRINTING
--------
Print with a resin printer.
Print using black-colored ABS-Like resin.
Print with NO SUPPORTS, just go straight to the print bed.
Print multiple sets: the upper spotlights only create one spot per lens.

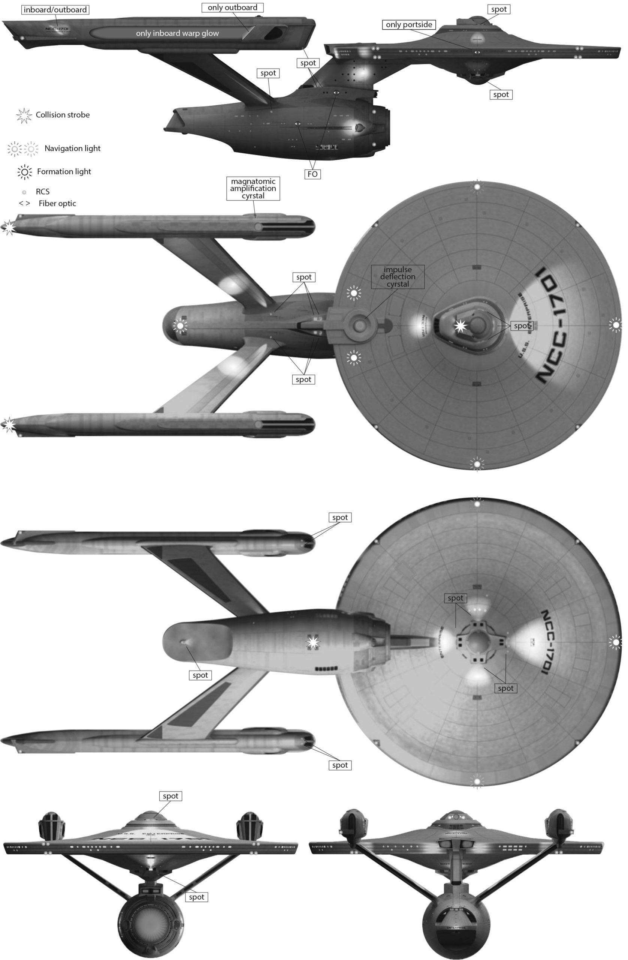
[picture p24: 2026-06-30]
Photos/Reference Diagram.jpg

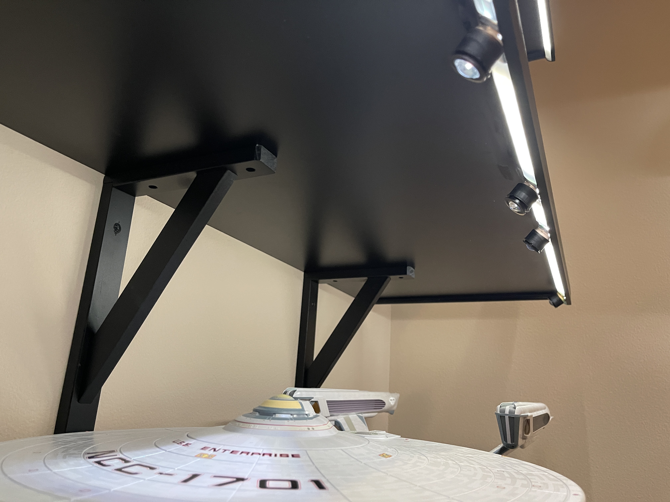
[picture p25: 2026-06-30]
Photos/Rail Low.jpg

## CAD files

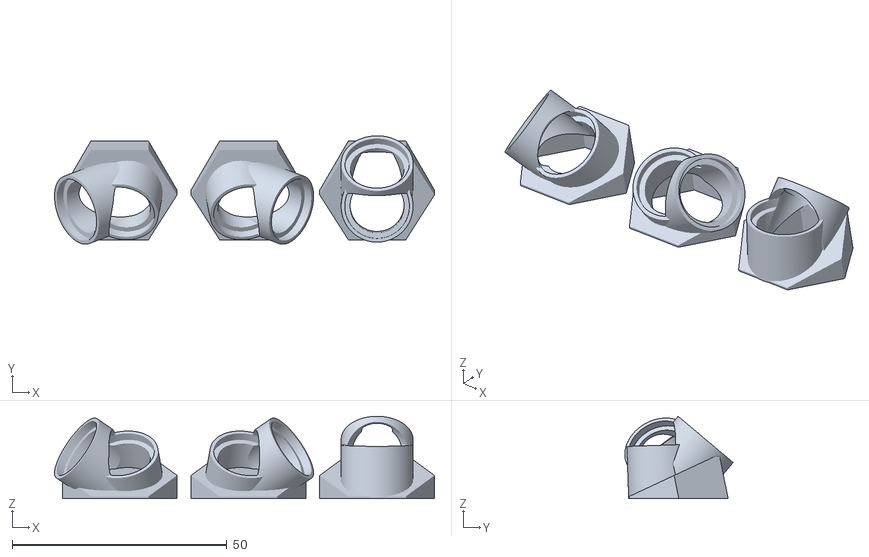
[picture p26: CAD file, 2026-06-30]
Lower Spotlights/Lower Spotlights.stl
88.6 x 25.3 x 19.2

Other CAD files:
Lower Spotlights/Lower Spotlights.blend
Upper Spotlights/Upper Spotlights.blend

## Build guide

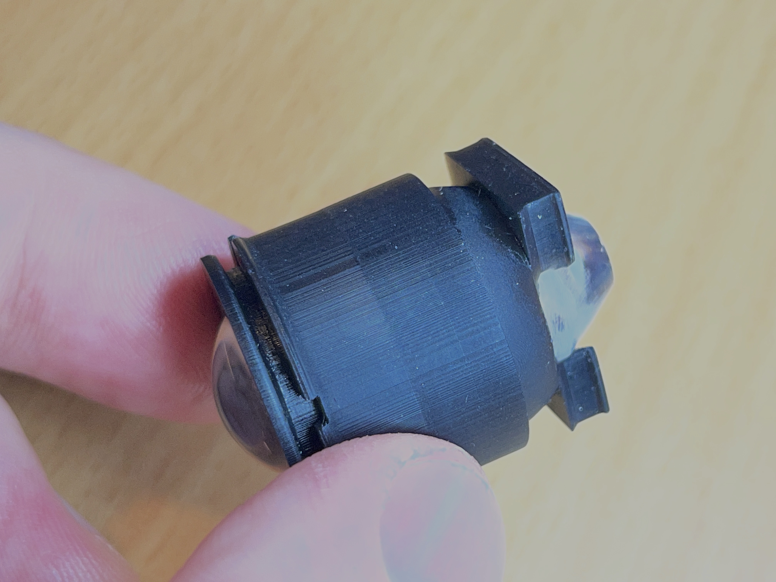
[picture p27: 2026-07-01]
Photos/Spotlight Assembled.jpg

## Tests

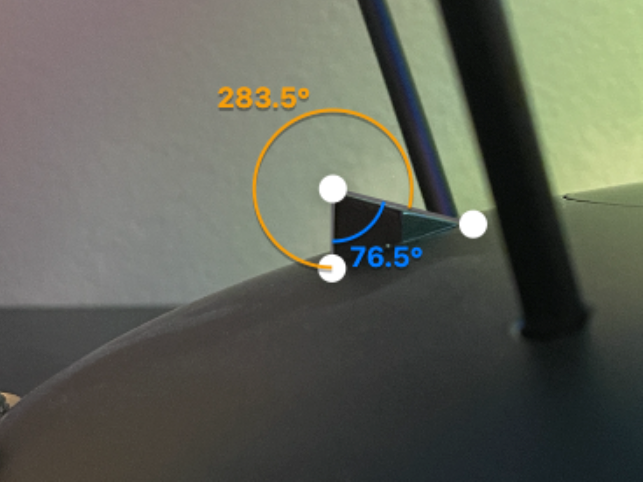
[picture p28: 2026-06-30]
Photos/Measure Angle of Hexagon Top vs Sides.png
